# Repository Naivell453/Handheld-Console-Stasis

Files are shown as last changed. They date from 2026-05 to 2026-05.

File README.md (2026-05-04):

# Handheld-Console-Stasis
A handheld console that has it's own OS, Model and Games (Stasis 2026 Project)

Hardware

The console is built around the Orange Pi Zero 2W (Allwinner H618, quad-core Cortex-A53, 1.5GB RAM). It features a 3.5" ILI9488 SPI display, stereo audio through two MAX98357A I2S amplifiers driving 4Ω 3W speakers, a 5000mAh LiPo battery with USB-C charging, and an MPU-6050 gyroscope for motion controls. Input is handled by 8 tactile push buttons arranged in a GBA-style layout.

Firmware

Built with Buildroot targeting the Orange Pi Zero 3 defconfig, which is compatible with the Zero 2W as both use the Allwinner H618 SoC.
To build:
bashgit clone https://github.com/buildroot/buildroot
cd buildroot
make orangepi_zero3_defconfig
make -j1
Flash output/images/sdcard.img to an SD card using Balena Etcher. The game launches automatically on boot with no password required.

Games

Ball Maze is a 2D physics-based maze game where the gyroscope controls the gravity direction. Rotating the console changes which way the ball falls, and the objective is to guide the ball out of the maze.
Platformer is a 2D side-scrolling platformer controlled with the D-pad and buttons.
FPS is a 3D first-person shooter with gyroscope-assisted aiming, currently in development.

PCB

Designed in EasyEDA and manufactured by JLCPCB. 2-layer through-hole design at 200mm × 90mm. The screen connects via SPI, the gyroscope via I2C, audio via I2S, and all buttons via GPIO pins on the Orange Pi header. Power is provided through an MT3608 boost converter stepping the battery voltage up to 5V.
Captura de pantalla 2026-04-09 232454
Captura de pantalla 2026-04-01 232801
Captura de pantalla 2026-04-02 114028
Captura de pantalla 2026-05-02 153729

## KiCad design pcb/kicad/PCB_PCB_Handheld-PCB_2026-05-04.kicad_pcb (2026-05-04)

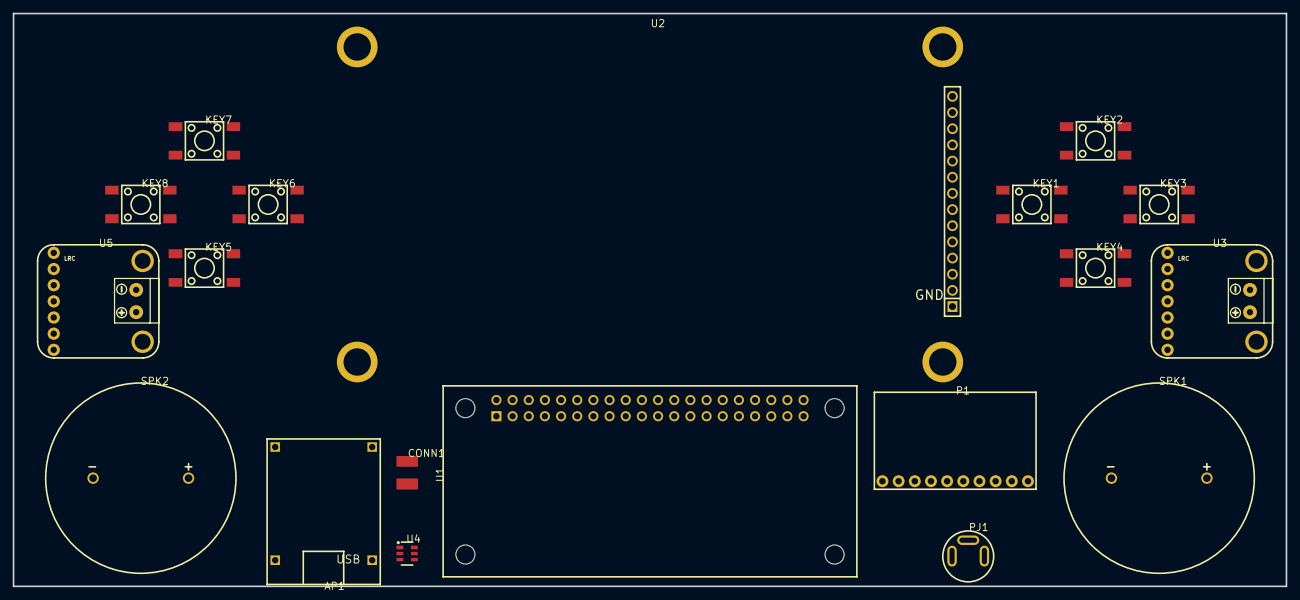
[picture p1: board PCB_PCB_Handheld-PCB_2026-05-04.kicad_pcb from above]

Board: 2 copper layers, 200.0 x 90.0 mm, 19 parts (0 on the bottom side), 26 nets, no tracks yet.

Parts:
AP1: TP4056 CHARGING MODDULE; TP4056-CHARGING-MODULE_TP4056
CONN1: CONN_01x02; CONN_01X02_SMD
KEY1, KEY2, KEY3, KEY4, KEY5, KEY6, KEY7, KEY8: 4PINTACTPCBTHTPUSHBUTTON; SW-SMD_4P-L6.0-W6.0-P4.50-LS10.0_TL3301EF160QG
P1: MPU6050
PJ1: PJ-3920-3A; AUDIO-TH_PJ-3920-3A
SPK1, SPK2: AST-03008MR-R; BEEP-TH_BD29.9-P15.00
U1: ORANGE-PI-ZERO-2W; COMM-TH_40P-L65.0-W30.0-P2.54_ORANGE-PI-ZERO-2W
U2: 3.5inch ILI9488 Display; 3.5INCH ILI9488
U3, U5: MAX98357A
U4: MT3608

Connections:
3V3: P1.1, U1.1, U1.17, U2.1, U2.8
5V: U1.2, U1.4, U3.1, U4.6, U5.1
12S_LRCK: U3.7, U5.7
BAT_P: AP1.1, CONN1.1
BTN_B: KEY1.1, U1.18
BTN_DOWN: KEY5.1, U1.26
BTN_LEFT: KEY8.1, U1.13
BTN_RIGHT: KEY6.1, U1.15, U1.16
BTN_SELECT: KEY4.1, U1.31
BTN_START: KEY3.1, U1.29
BTN_UP: KEY7.1, U1.7
GND: AP1.2, CONN1.2, KEY1.2, KEY2.2, KEY3.2, KEY4.2, KEY5.2, KEY6.2, KEY7.2, KEY8.2, P1.2, PJ1.1, U1.6, U1.9, U1.14, U1.20, U1.25, U1.30, U1.34, U1.39, U2.2, U3.2, U4.2, U5.2
I2C_SCL: P1.3, U1.5
I2C_SDA: P1.4, U1.3
I2S_BCLK: U1.12, U3.6, U5.6
I2S_DIN: U1.38, U3.5, U5.5
LCD_DC: U1.22, U2.5
LCD_RST: U1.11, U2.4
SPI_CS: U1.24, U2.3
SPI_MISO: U1.21, U2.9
SPI_MOSI: U1.19, U2.6
SPI_SCK: U1.23, U2.7
SPKR_L_N: SPK2.2, U5.8
SPKR_L_P: PJ1.3, SPK2.1, U5.9
SPKR_R_N: SPK1.2, U3.8
SPKR_R_P: PJ1.2, SPK1.1, U3.9

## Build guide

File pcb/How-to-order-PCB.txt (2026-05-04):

How to Order PCB

Please refer to:
https://docs.easyeda.com/en/PCB/Order-PCB

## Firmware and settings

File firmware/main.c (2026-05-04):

/*
 * Stasis Console Firmware
 * Built with Buildroot for Orange Pi Zero 2W (Allwinner H618, ARM64)
 * 
 * Build system: Buildroot
 * Target: Orange Pi Zero 3 defconfig (compatible with Zero 2W)
 * Autorun: /etc/init.d/S99game
 * Game engine: Godot 4.6
 * 
 * To build:
 * make orangepi_zero3_defconfig
 * make -j1
 */

int main() {
    return 0;
}

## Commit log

2026-05-04 Added PCB
    [PickAndPlace_PCB_Handheld-PCB_2026-05-02.csv]
2026-05-04 Created pcb folder
2026-05-04 Created pcb folder gerber
2026-05-04 Added gerber pcb files
    [Drill_NPTH_Through.DRL, Drill_PTH_Through.DRL, Drill_PTH_Through_Via.DRL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]
2026-05-04 Created kicad folder
2026-05-04 Added Kicad PCB
    [PCB_PCB_Handheld-PCB_2026-05-04.kicad_pcb]
